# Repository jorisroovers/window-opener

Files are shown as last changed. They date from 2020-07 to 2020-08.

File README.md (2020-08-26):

# WindowOpener

I built a custom PCB in a 3D-printed enclosure to control a motorized arm to automatically open and close my bedroom window. 
All integrated with [my existing home automation stack](https://github.com/jorisroovers/casa). **For much more detail, read my [Window Opener blogpost](https://jorisroovers.com/posts/window-opener).**

This repository contains all related source material.

# Repository Structure
- `PCB/`: PCB related files in various formats. For easy editing, use the json file to import into [EasyEDA](https://easyeda.com/).
- `esphome/`: [ESPHome](https://esphome.io/) config files
- `CAD/`: CAD (3D) models of the enclosure and custom hinges that were 3D printed. I used [Fusion360](https://www.autodesk.com/products/fusion-360/personal).
- `diagrams/`: Some diagrams in [Fritzing](https://fritzing.org/) and [KiCad](https://kicad-pcb.org/). Some of these are not entirely up-to-date with the latest build, but they should still be useful if you want to understand some of the details.
- `gcode/`: gcode files to print the 3D models. These are mostly for my own consumption as you'll probably have re-slice the STL files in the `CAD/` folder to match your printer and filament.
- `collage/`: files related to a project collage I made to put up on the wall
- `archive/`: various files related to prototyping and experimentation

# ESPHome

# Flashing firmware to ESP8266 device

## secrets.yaml
The `window_opener.yaml` has secret values which are read by ESPHome from  `secrets.yaml` at compile-time.
So for this to work, you'll need to create a `secrets.yaml` file that looks like the following.
```yaml
deviceid: my_device_id
devicename: "Human Friendly Device Name"

wifi_ssid: mywifissid
wifi_password: "mypassword"
wifi_static_ip: 10.0.0.2
wifi_gateway: 10.0.0.1
wifi_subnet: 255.255.255.0
wifi_fallback_ap_password: "WifiFallbackPassword"
wifi_fallback_ap_ssid: ESP-FallbackWifi
api_password: "apipassword"
ota_password: "otapassword"
```

## Instructions

The first time doing this, the ESP device will need to be connected to your computer using a serial connection.
After the first run, you can do this over Wifi (ESPHome supports over-the-air firmware updates).

```sh
virtualenv .venv && source .venv/bin/activate
pip install esphome

esphome esphome/window_opener.yaml run
# Specify serial port
esphome esphome/window_opener.yaml run --upload-port /dev/cu.usbserial-143230
```

# Homeassistant Integration

Use the 'integrations' page in home-assistant to connect to the ESPHome device.

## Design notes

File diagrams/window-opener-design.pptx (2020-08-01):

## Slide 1

Window

Automation Rules:
IF housemode == Sleep OR
housemode == Away OR
weather == raining OR
bedroom_heater.status == ON OR
time == 5AM OR
…
THEN Close Window

Home Server

Homeassistant

Home-automation
system

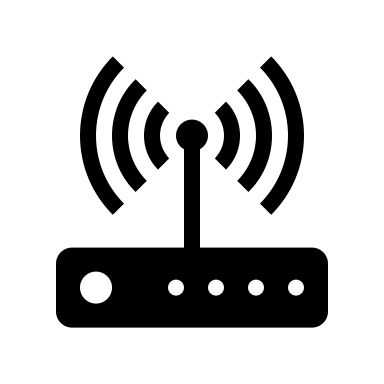
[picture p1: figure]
Wireless router

WiFi

opening
widget

Micro-controller

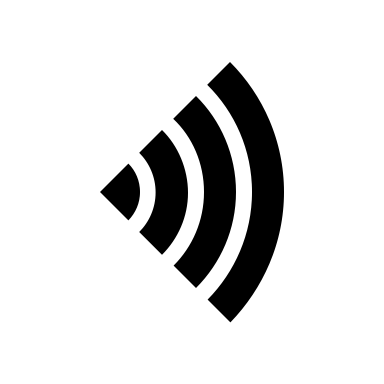
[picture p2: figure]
Wi Fi
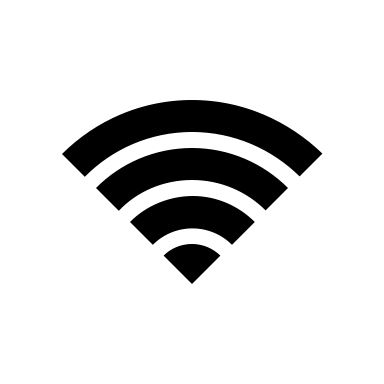
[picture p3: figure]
Wi Fi

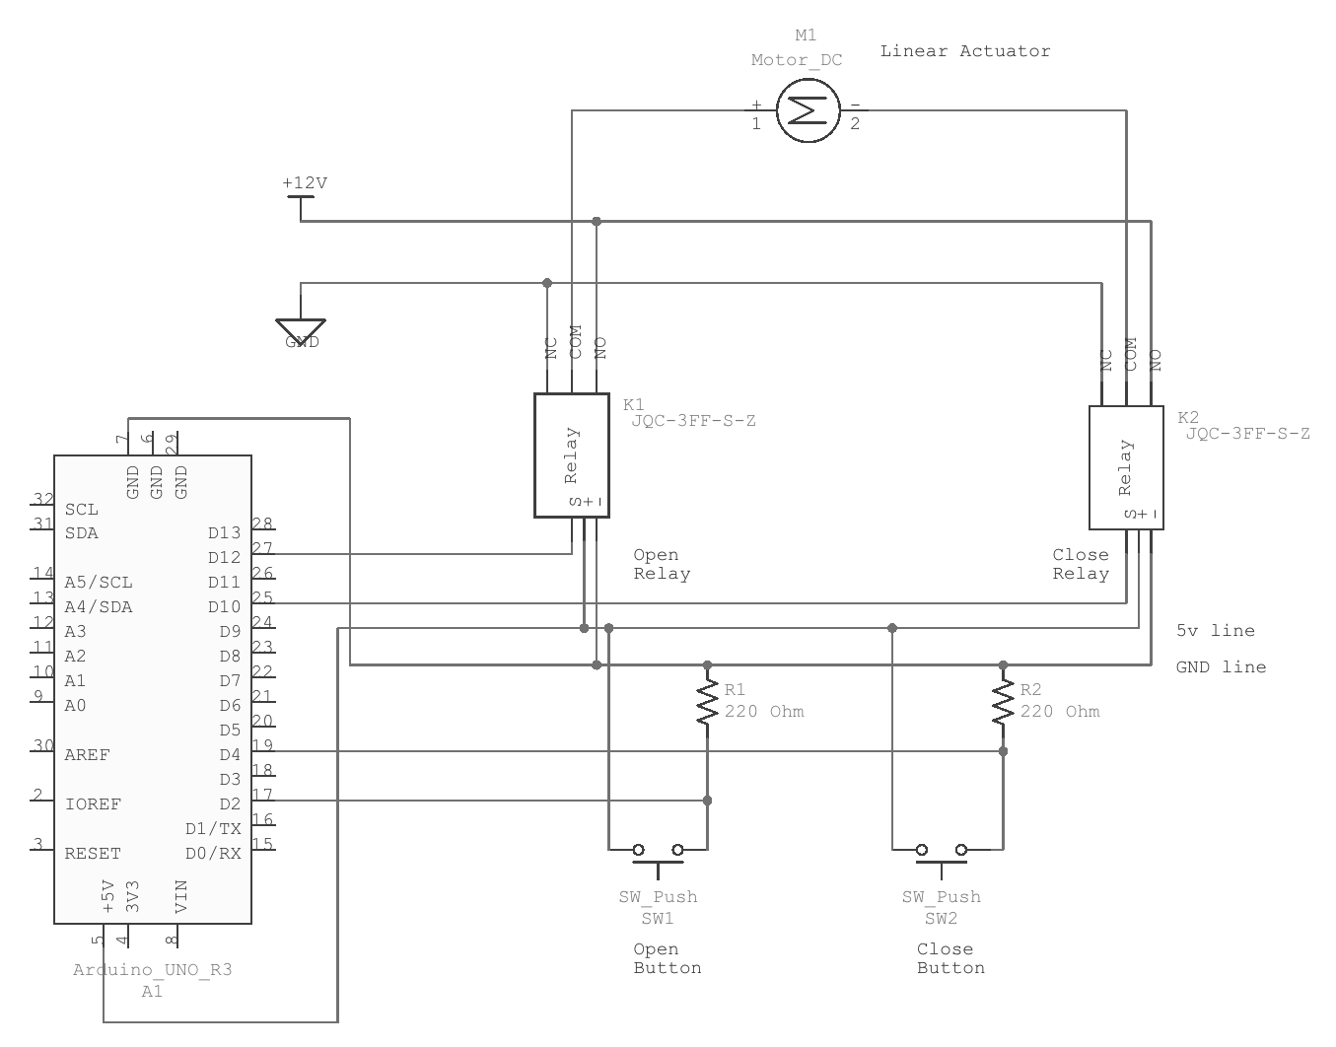
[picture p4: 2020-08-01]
collage/schematic-grayscale_1.png

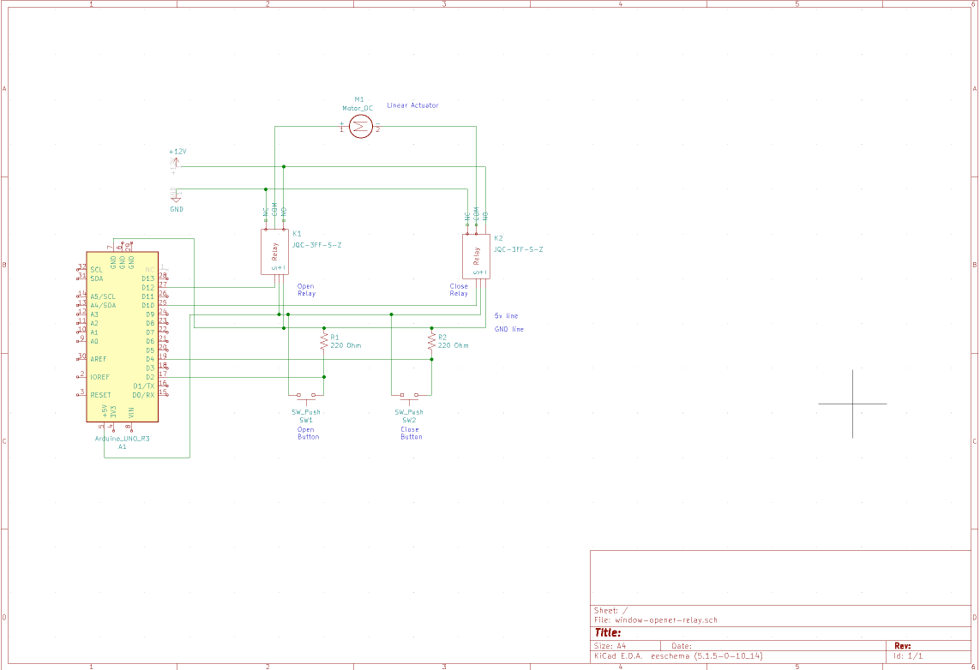
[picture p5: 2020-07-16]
diagrams/schematic.png

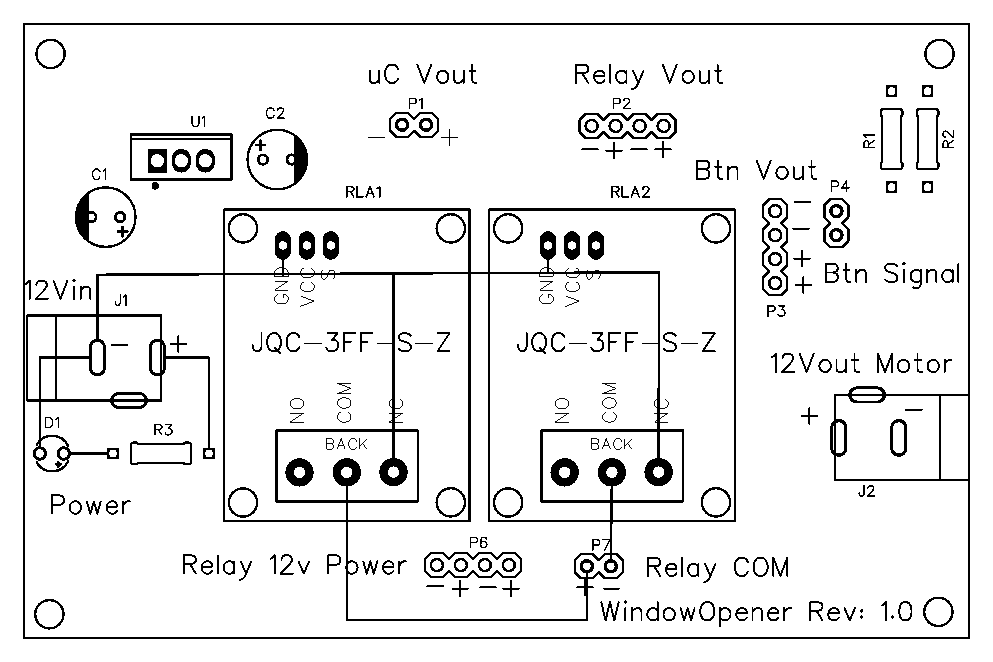
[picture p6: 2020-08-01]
collage/PCB_PCB-Window-Opener-v1_1.png

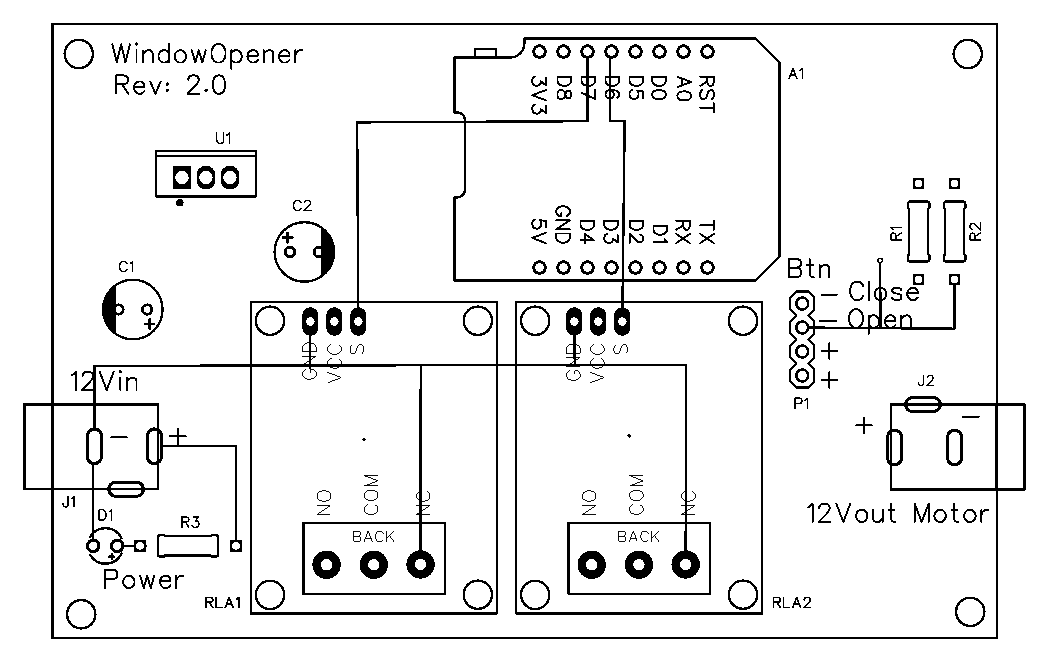
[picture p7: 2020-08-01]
collage/PCB_PCB-Window-Opener-v2_1.png

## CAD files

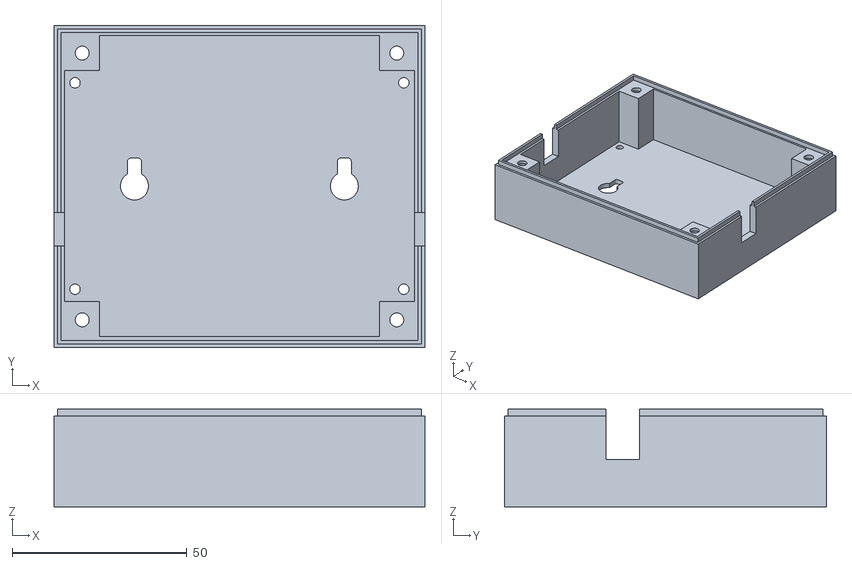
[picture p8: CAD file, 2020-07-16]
CAD/Enclosure/Bottom.stl
106.1 x 92.0 x 28.0

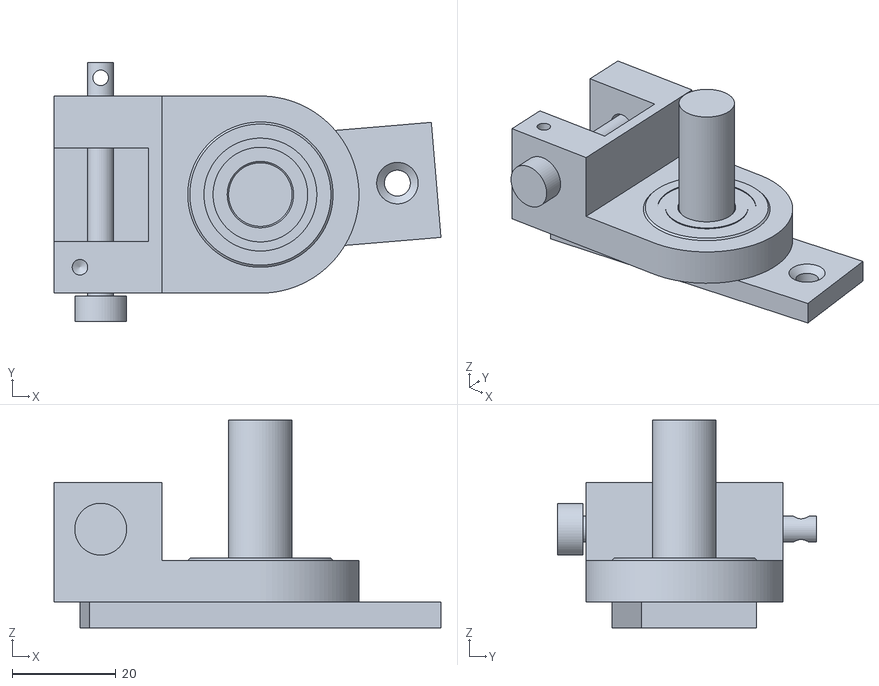
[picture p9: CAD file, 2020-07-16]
CAD/Wall-Joint/wall-joint-rev2 v18.stl
74.6 x 50.0 x 40.0

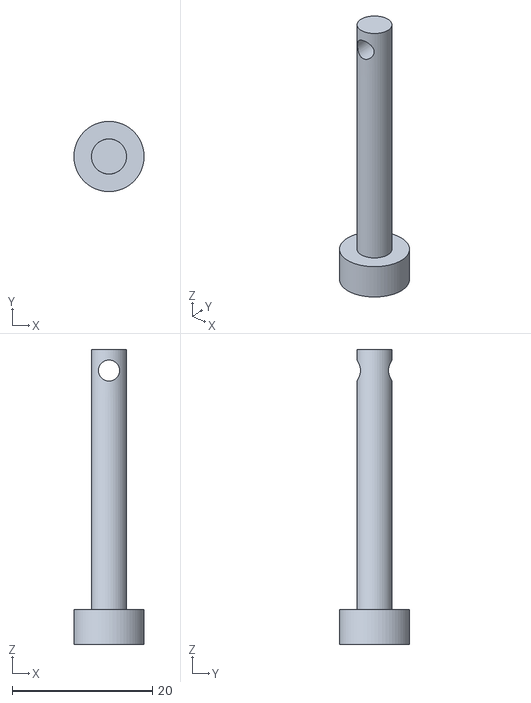
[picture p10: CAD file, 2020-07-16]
CAD/Window-Hinge/Pin.stl
10.0 x 10.0 x 42.0

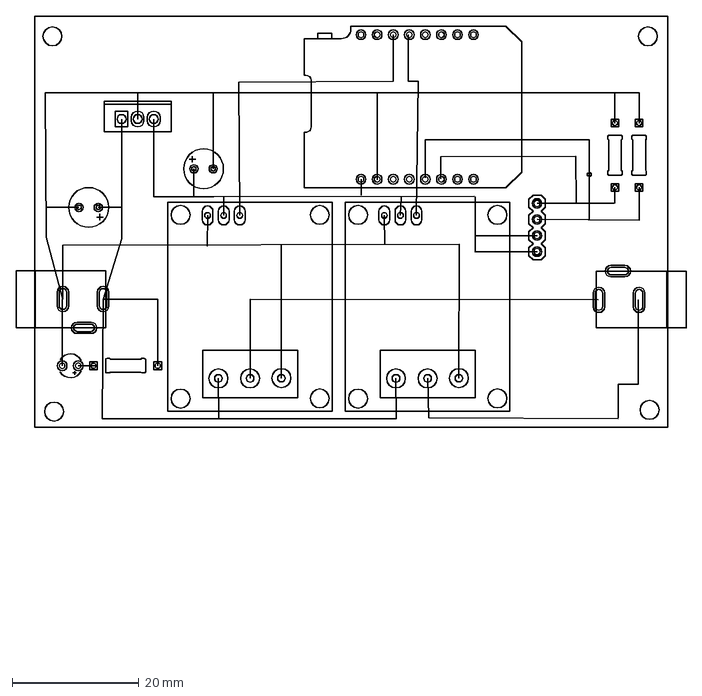
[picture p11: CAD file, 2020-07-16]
PCB/v2/PCB-Window-Opener-v2.dxf
105.9 x 101.1 mm

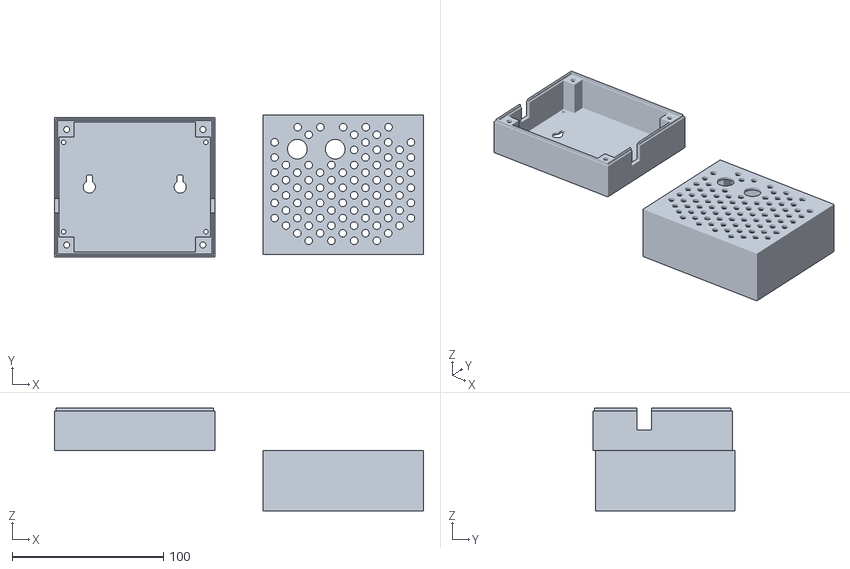
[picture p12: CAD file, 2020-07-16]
CAD/Enclosure/Enclosure v29.stl
243.6 x 93.6 x 68.0

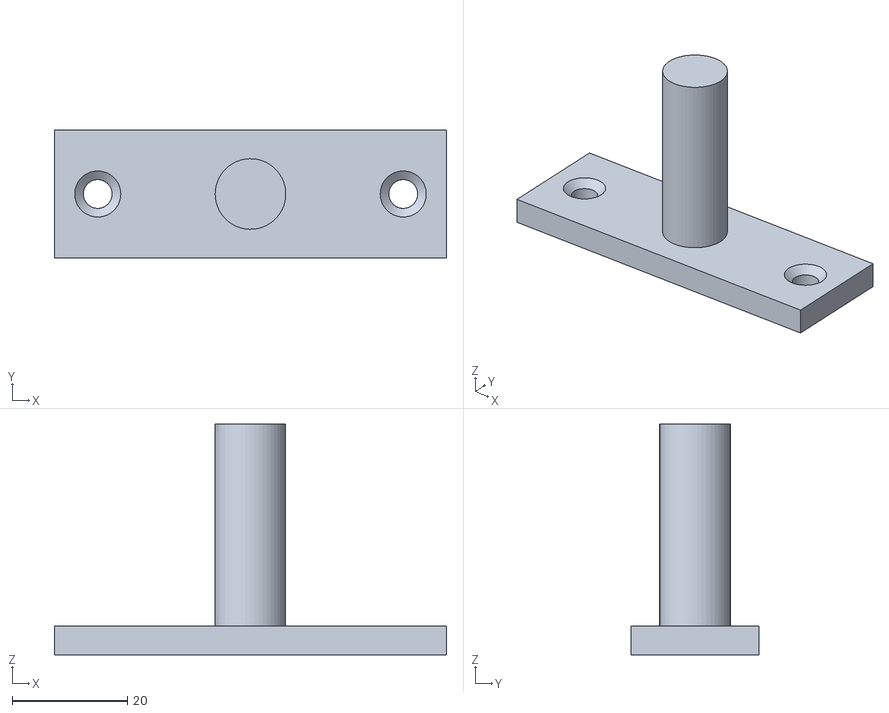
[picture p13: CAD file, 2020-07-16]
CAD/Wall-Joint/Window-frame-attachment.stl
68.0 x 22.3 x 40.0

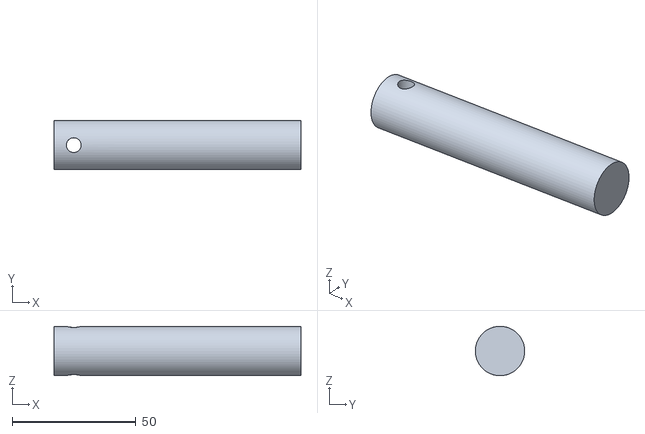
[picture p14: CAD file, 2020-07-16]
CAD/Window-Hinge/Actuator Rod.stl
100.0 x 20.0 x 20.0

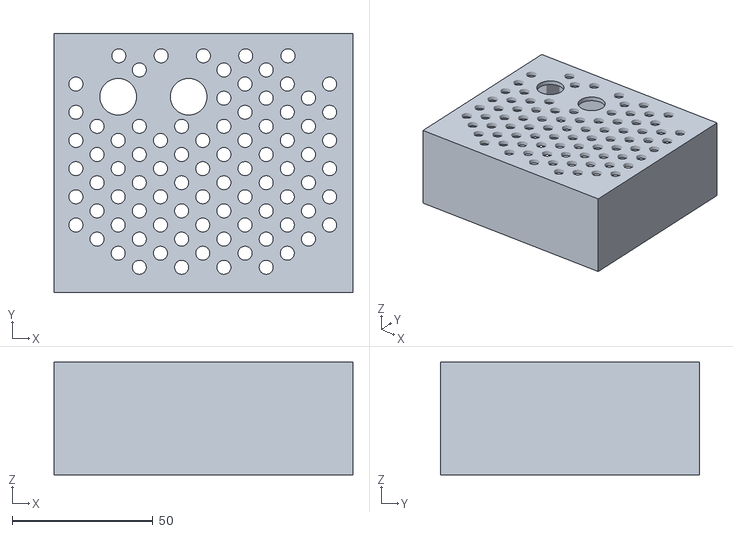
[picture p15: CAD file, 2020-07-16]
CAD/Enclosure/Top.stl
106.1 x 92.0 x 40.0

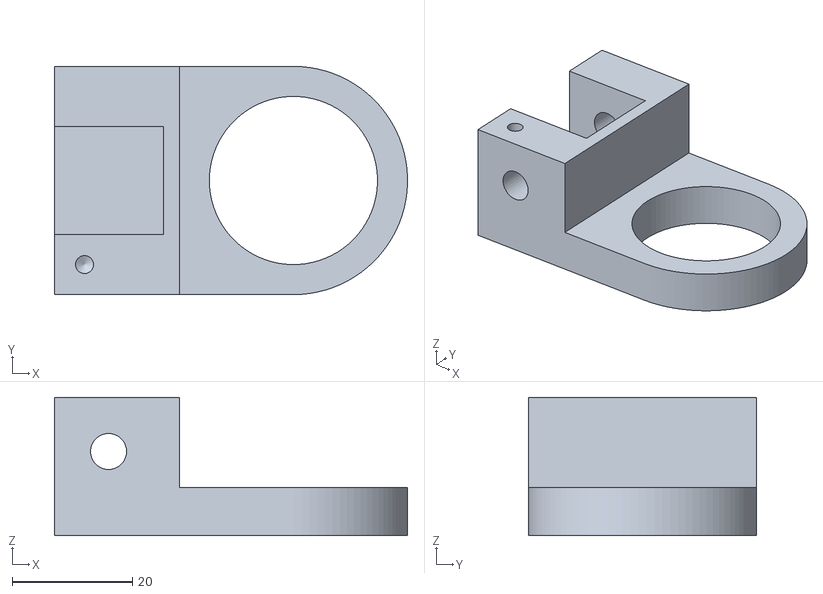
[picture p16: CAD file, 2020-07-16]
CAD/Wall-Joint/Motor-attachment.stl
58.8 x 38.0 x 23.0

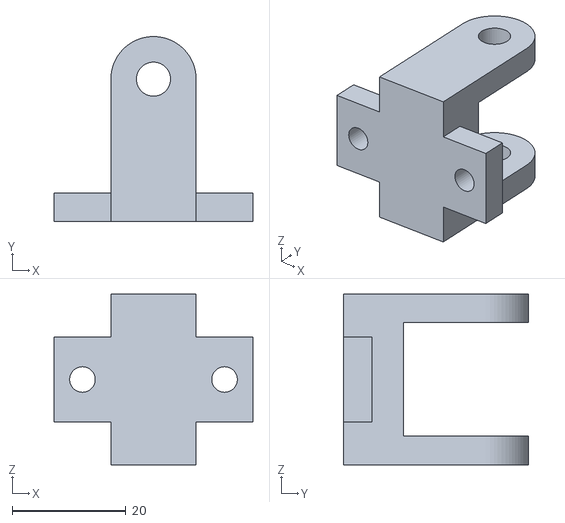
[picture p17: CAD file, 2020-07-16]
CAD/Window-Hinge/Hinge.stl
35.0 x 32.5 x 30.0

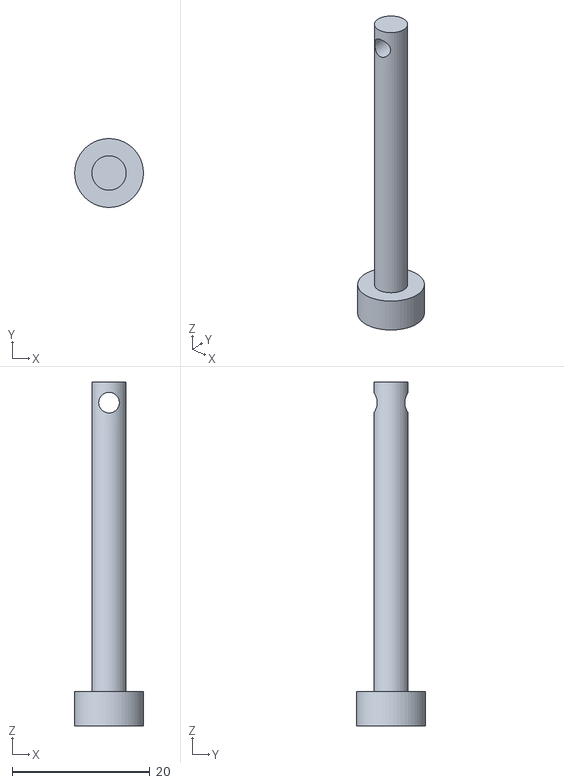
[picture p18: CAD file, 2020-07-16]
CAD/Wall-Joint/Pin.stl
9.99 x 10.00 x 50.0

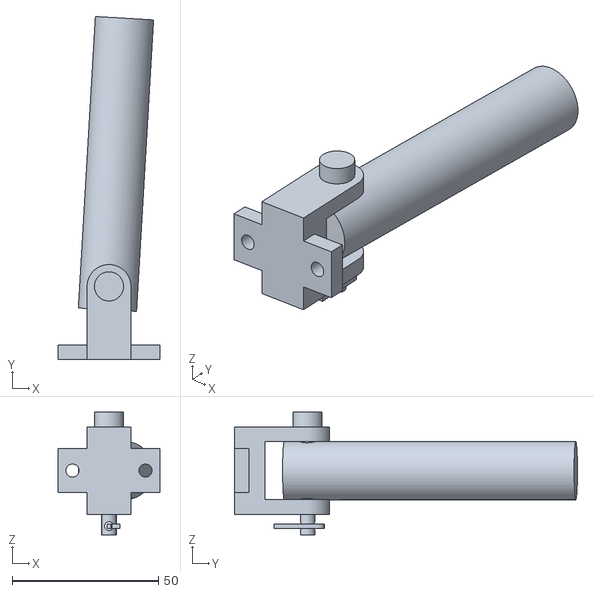
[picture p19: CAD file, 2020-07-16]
CAD/Window-Hinge/Window-hinge v19.stl
35.0 x 117.5 x 42.0

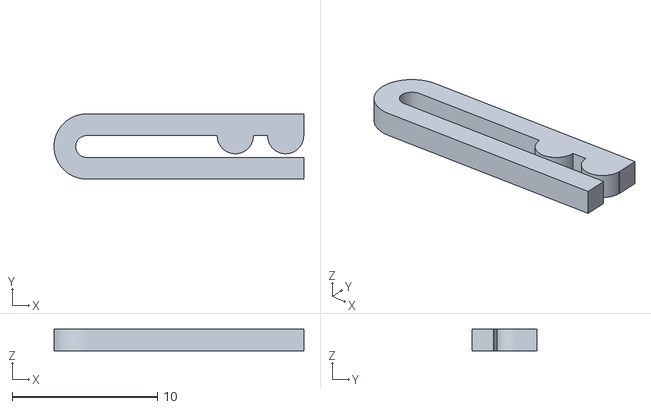
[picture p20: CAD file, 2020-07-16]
CAD/Window-Hinge/Safety Clip.stl
17.2 x 4.49 x 1.50

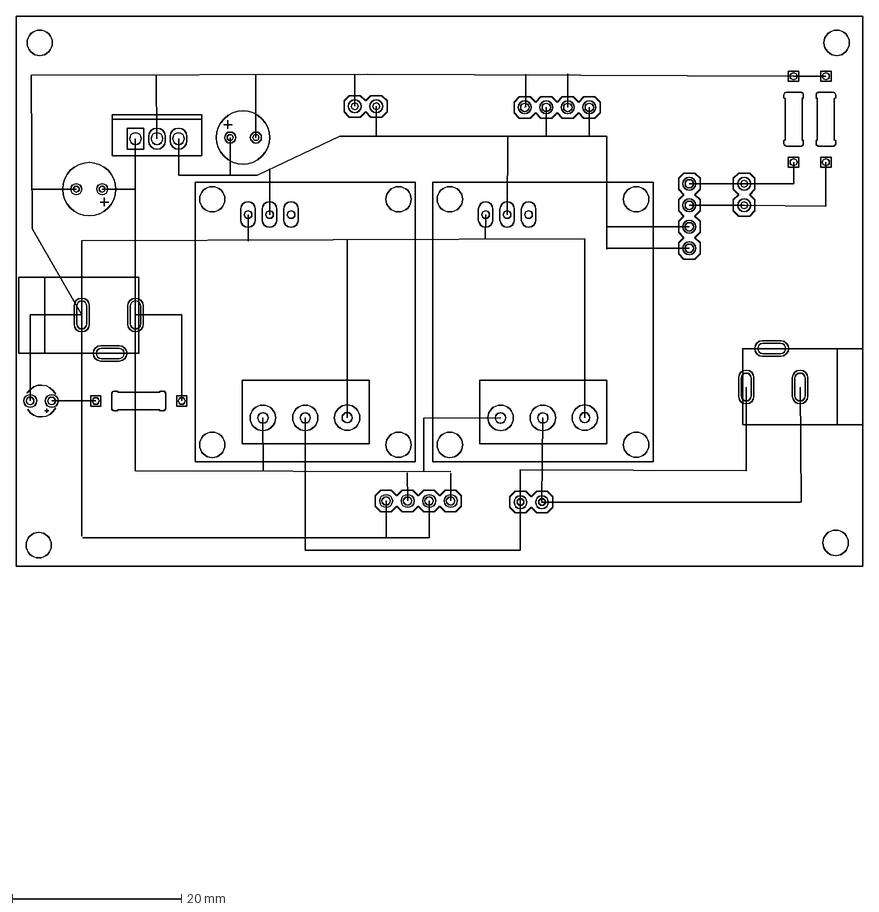
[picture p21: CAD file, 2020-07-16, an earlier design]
PCB/v1/PCB-Window-Opener-v1.dxf
100.0 x 101.1 mm

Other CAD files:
collage/Window-Opener-Drawing-Source Drawing v9.dwg
collage/Window-Opener-Drawing-Source Drawing v9 - simplified DWG.dwg
CAD/Enclosure/Enclosure v29.dwg
CAD/Enclosure/Enclosure v29.f3d
CAD/Wall-Joint/wall-joint-rev2 v18.dwg
CAD/Wall-Joint/wall-joint-rev2 v18.f3d
CAD/Window-Hinge/Window-hinge v19.dwg
CAD/Window-Hinge/Window-hinge v19.f3d

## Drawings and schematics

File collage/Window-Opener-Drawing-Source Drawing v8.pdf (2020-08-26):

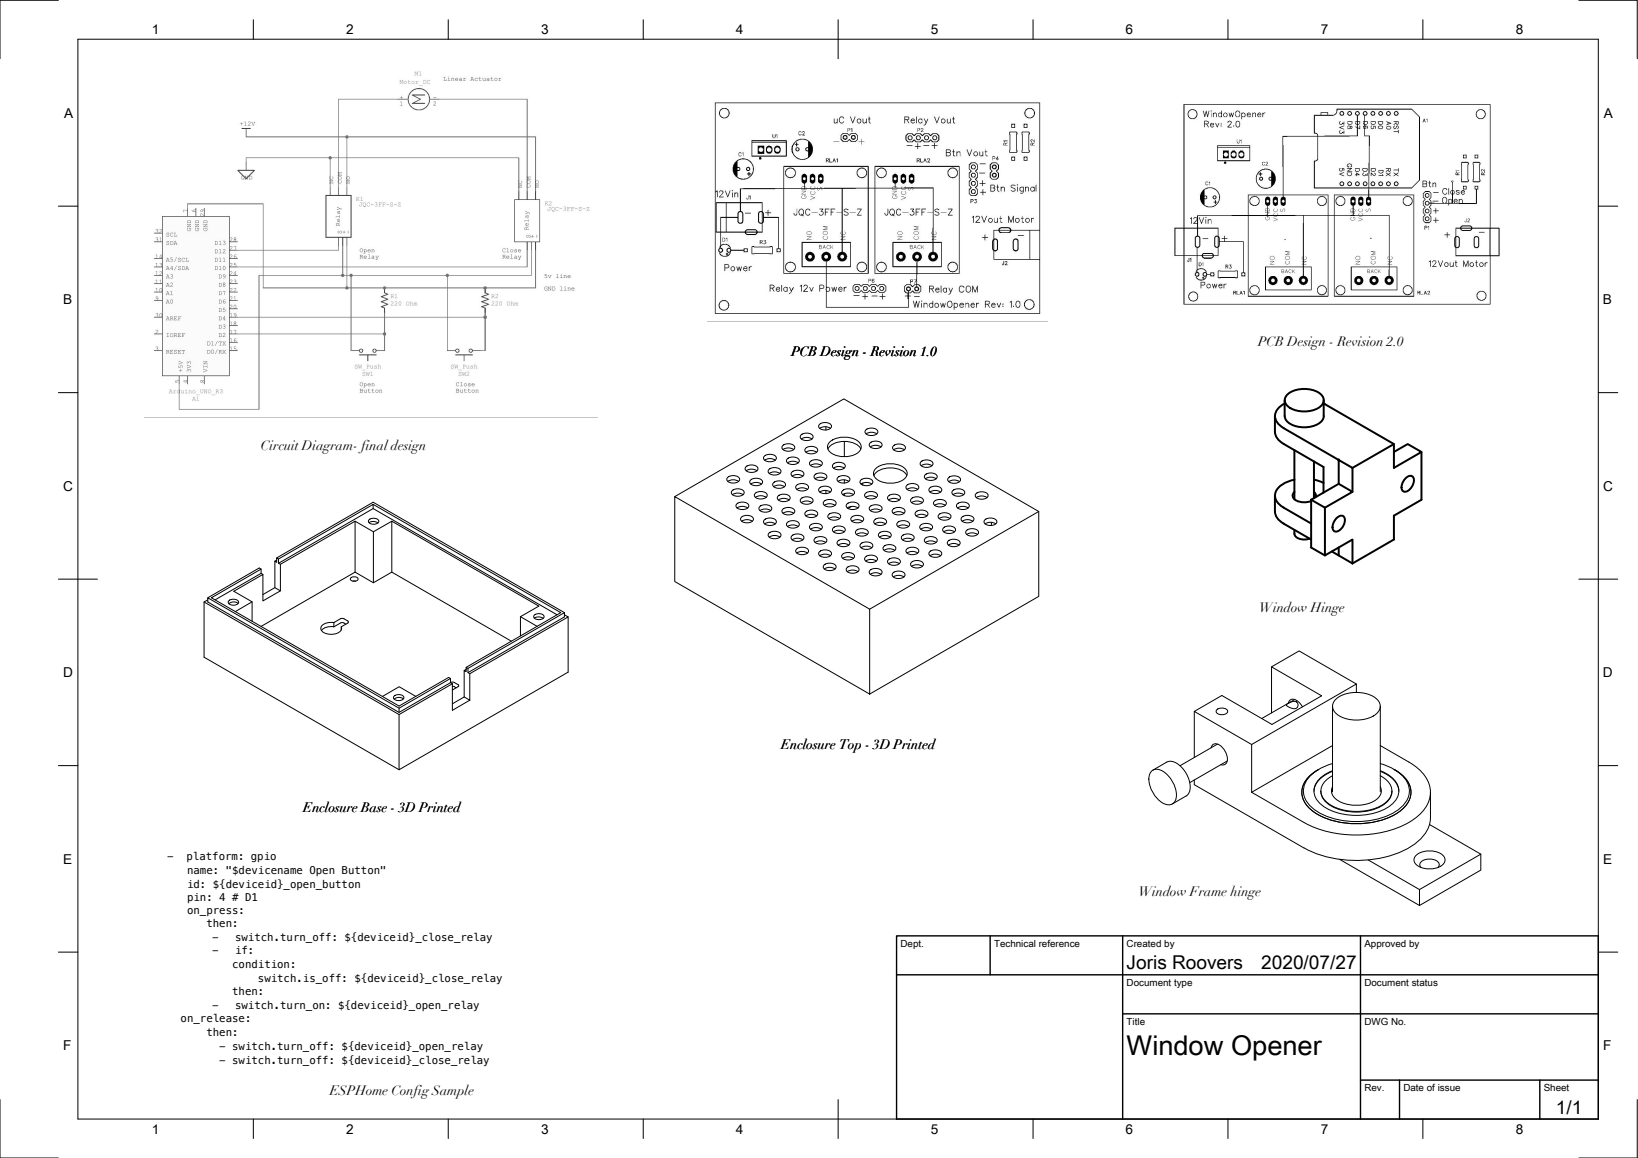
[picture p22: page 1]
PCB Design - Revision 1.0; PCB Design - Revision 2.0; Window Hinge

Circuit Diagram- final design

Enclosure Top - 3D Printed

Enclosure Base - 3D Printed

- platform: gpio
name: "$devicename Open Button"
id: ${deviceid}_open_button
pin: 4 # D1
on_press:
then:
- switch.turn_off: ${deviceid}_close_relay
condition:
switch.is_off: ${deviceid}_close_relay
- switch.turn_on: ${deviceid}_open_relay
on_release:
- switch.turn_off: ${deviceid}_open_relay

Window Frame hinge

Dept. | Technical reference | Created by Joris Roovers 2020/07/27 | Approved by

Document type | Document status

Title Window Opener | DWG No.

ESPHome Config Sample

Rev. | Date of issue | Sheet 1/1

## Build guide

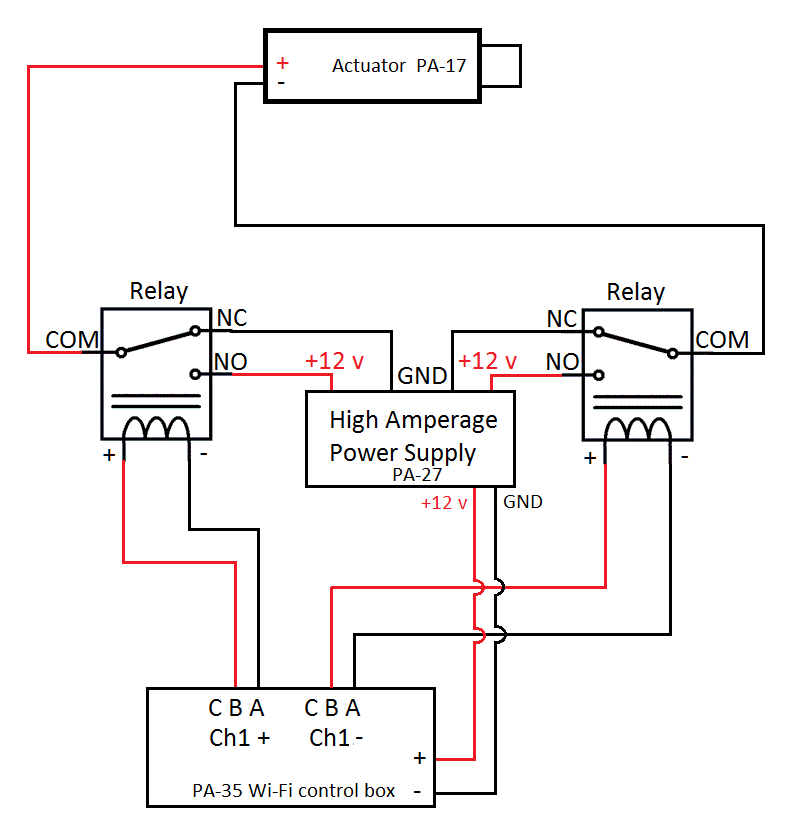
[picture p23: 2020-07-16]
diagrams/relay-linear-actuator-wiring.png

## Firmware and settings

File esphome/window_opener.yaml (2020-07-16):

########################################################################################################################
# General ESPHome config                                                                                               #
########################################################################################################################
substitutions:
  deviceid: !secret deviceid
  devicename: !secret devicename

esphome:
  name: ${deviceid}
  platform: ESP8266
  board: d1 # optional, only affects pin layout
  # on boot: close both relays (so we don't have any shenanigans when power cycling)
  on_boot:
    then:
      - switch.turn_off: ${deviceid}_open_relay
      - switch.turn_off: ${deviceid}_close_relay

wifi:
  ssid: !secret wifi_ssid
  password: !secret wifi_password
  manual_ip:
    static_ip: !secret wifi_static_ip
    gateway: !secret wifi_gateway
    subnet: !secret wifi_subnet

  # Enable fallback hotspot (captive portal) in case wifi connection fails
  ap:
    ssid: !secret wifi_fallback_ap_ssid
    password: !secret wifi_fallback_ap_password

captive_portal:

# Enable logging
logger:

# Enable Home Assistant API
api:
  password: !secret api_password

ota:
  password: !secret ota_password

########################################################################################################################
# I/O                                                                                                                  #
########################################################################################################################
# Notes:
# - The switching logic below contains some extra checks and actions to ensure (and double ensure) that both relays
#   are never engaged at the same time, as this can cause a short-circuit in the linear actuator that opens the window.
# - If homeassistant changes the relay states while a button is pressed, releasing the button will automatically cancel
#   the signal coming from homeassistant. This is a good safety.

# INPUTS: REED SENSOR & BUTTONS
binary_sensor:
#   - platform: gpio
#     name: "$devicename Window Status"
#     id: ${deviceid}_status
#     pin: 4 # D2
#     filters:
#       - invert: # magnet detected => 'off' (window closed), no magnet => 'on' (window open)

  - platform: gpio
    name: "$devicename Open Button"
    id: ${deviceid}_open_button
    pin: 4 # D1
    on_press:
      then:
        # turn off the other relay, but double check (=if) before turning on this one to ensure we don't turn them
        # on at the same time.
        - switch.turn_off: ${deviceid}_close_relay
        - if:
            condition:
              switch.is_off: ${deviceid}_close_relay
            then:
              - switch.turn_on: ${deviceid}_open_relay
   # on_release: turn both relays off, this is just an extra safety to avoid having both relays on at the same time.
    on_release:
      then:
        - switch.turn_off: ${deviceid}_open_relay
        - switch.turn_off: ${deviceid}_close_relay

  - platform: gpio
    name: "$devicename Close Button"
    id: ${deviceid}_close_button
    pin: 5 # D2
    on_press:
      then:
        - switch.turn_off: ${deviceid}_open_relay
        - if:
            condition:
              switch.is_off: ${deviceid}_open_relay
            then:
              - switch.turn_on: ${deviceid}_close_relay
    on_release:
      then:
        - switch.turn_off: ${deviceid}_open_relay
        - switch.turn_off: ${deviceid}_close_relay

# OUTPUTS: RELAYS
switch:
  - platform: gpio
    name: "$devicename Open Relay"
    id: ${deviceid}_open_relay
    pin: 12 # D6, D5=14
    # if we turn on this relay, automatically turn off the other one.
    # Required for when switching from home-assistant.
    on_turn_on:
      - then:
          - switch.turn_off: ${deviceid}_close_relay

  - platform: gpio
    name: "$devicename Close Relay"
    id: ${deviceid}_close_relay
    pin: 13 # D7
    on_turn_on:
      - then:
          - switch.turn_off: ${deviceid}_open_relay


# TODO (important): Open switch that opens and stops after 2 seconds, so that 
# switch:
#   - platform: gpio
#     name: "$devicename Open Window"
#     id: ${deviceid}_open
#     pin: 12 # D6, D5=14
#     # if we turn on this relay, automatically turn off the other one.
#     # Required for when switching from home-assistant.
#     on_turn_on:
#       - then:
#           - switch.turn_off: ${deviceid}_close_relay

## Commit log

2020-07-16 Initial source material upload
    [Actuator Rod.stl, Bottom.stl, Enclosure v29.dwg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]
2020-08-01 gcode files for easy printing
2020-08-26 Collage files
    Files related to a project collage I made to put up on the wall.
    [Window-Opener-Drawing-Source Drawing v9 - simplified DWG.dwg, Window-Opener-Drawing-Source Drawing v9.dwg]
